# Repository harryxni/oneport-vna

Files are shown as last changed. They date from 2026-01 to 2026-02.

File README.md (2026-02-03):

# **One Port VNA**

 My attempt at designing a one port VNA and to learn some RF fundamentals and technqiues. The goal here is to build a simple working S11 (reflection) VNA with minimal RF complexity.

## Architecture

The design will be based around the ADL 5960, a VNA frontend that should simplify many design considerations by black-boxing a few components of typical VNAs. Besides the ADL 5960, we will require an ADC stage, digital processing, and an RF source and a clock source.

Let's set some target design specs:

* Frequency: 10 MHz - O(1) GHz

* TBD

## Repo Structure

- kicad/ Schematic and PCB design files

- docs/ Notes on design and theory, block diagrams, data sheets and user guides

- firmware/ ADC, FPGA code etc.

- simulations/ SPICE, RF simulations

- fabrication/ Fabrication outputs by kicad

- scripts/ Data processing and plotting

## Results

Results will be posted here as I progress. 

#### Step 1: Simulating Idealized Components

GOAL: Develop a system-level simulation using idealized components to return $\Gamma$ and $S_{11}$. It will consist of a voltage source (V_1), a source impedance ($R_{\text{src}}$) and a DUT ($R_{\text{load}}$).

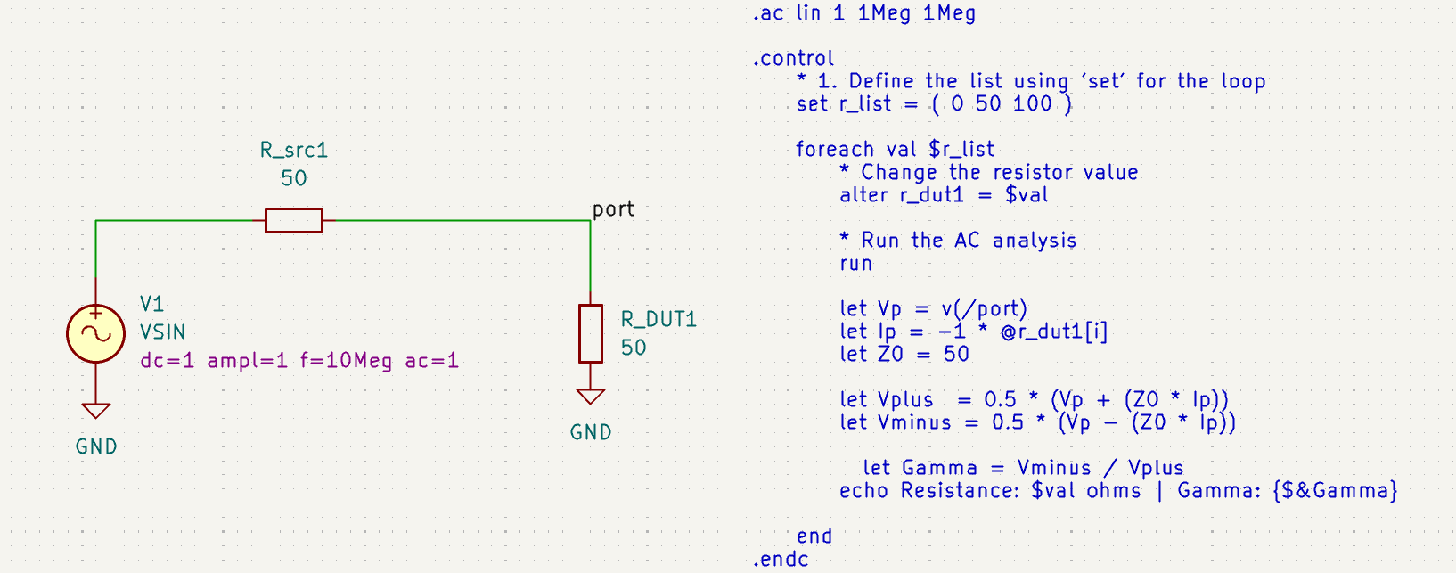
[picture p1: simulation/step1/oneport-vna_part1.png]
 

The schematic and ngspice directive is shown above. 

A few notes on this...KiCAD has some quirks when running spice simulations (coming from xschem). Specifically, running plotting commands within .control does not work since KiCAD uses its own plotting software. This creates an issue since defining vectors and variables within the KiCAD simulator and plotter is very clunky. Here, I remedy this by running a single point in the .ac analysis and just printing $\Gamma$, since I don't expect any change at different frequencies. In the future, I'll have to use wrdata to export data and use python to plot. Also, .step does not work in KiCAD, so I had to use a foreach loop which edits the resistance of R_DUT, rather than setting a param and stepping through.

Results are below with some of the spice output cleaned up. They are as expected...

```
Resistance: 0 ohms | Gamma: -1
Resistance: 50 ohms | Gamma: 0
Resistance: 100 ohms | Gamma: 0.333333
```

#### Step 2: A more realistic simulation

GOAL: Introduce realistic imperfection into the model, such as parasitics and source matching errors and using a realistic coupler (ie a Return loss bridge) to model effects of error in measurement. 

##### 2a: VNA with Parasitics

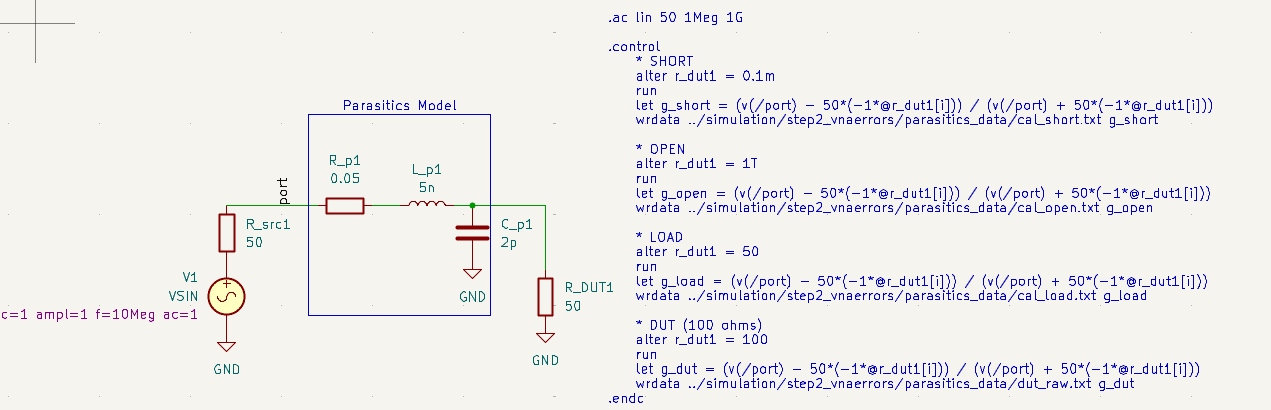
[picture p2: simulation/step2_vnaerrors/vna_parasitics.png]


In this model, we've simply introduced a set of parasitics: a series resistor and inductor and a shunt capacitor, with some arbitrary values. We run the simulation in 4 different scenarios: Open, Short, Load match (OSL) and a DUT ($R_{load}=100$  $\Omega$). The OSL measurement provides a calibration for the errors which are introduced via the parasitics. These are then calculated and used to correct for the DUT measurement.

The exact calculations and data processing are done in [this notebook](simulation/step2_vnaerrors/). The results of the OSL measurements are shown here:

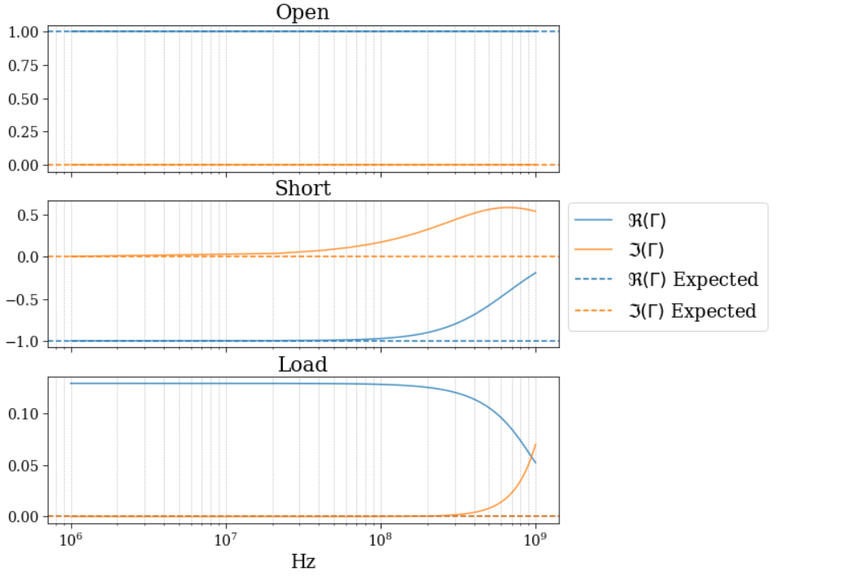
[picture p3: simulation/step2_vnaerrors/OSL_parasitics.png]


Using these measurements in comparison to the expected values, we calculate out the error terms ($E_{dl}$, $E_{sf}$ and $E_{rf}$) and use them for the correct $\Gamma_{DUT}$ measurement:

$\Gamma= \frac{\Gamma_m -E_{dl}}{E_{rf} + E_{sf}(\Gamma_m - E_{dl})}$

The effects of this correction are shown below and compared to the expected value. 

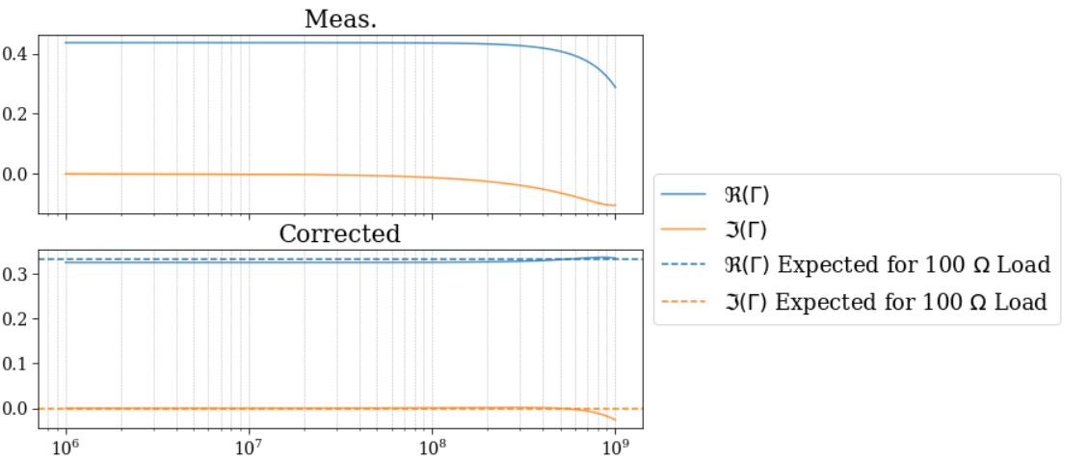
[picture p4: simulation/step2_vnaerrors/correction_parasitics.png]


##### 2b: VNA with Directional Coupling

Here, we will simulate the directional coupling found in the ALD5960 by implementing a bridge. I believe it is simplest to just use a wheatstone bridge in this case, since the ALD5960 does a lot of the handling of the RLB measurements. 

I've addded some parasitics in the system as well. 

Below shows the simulated ciruit:

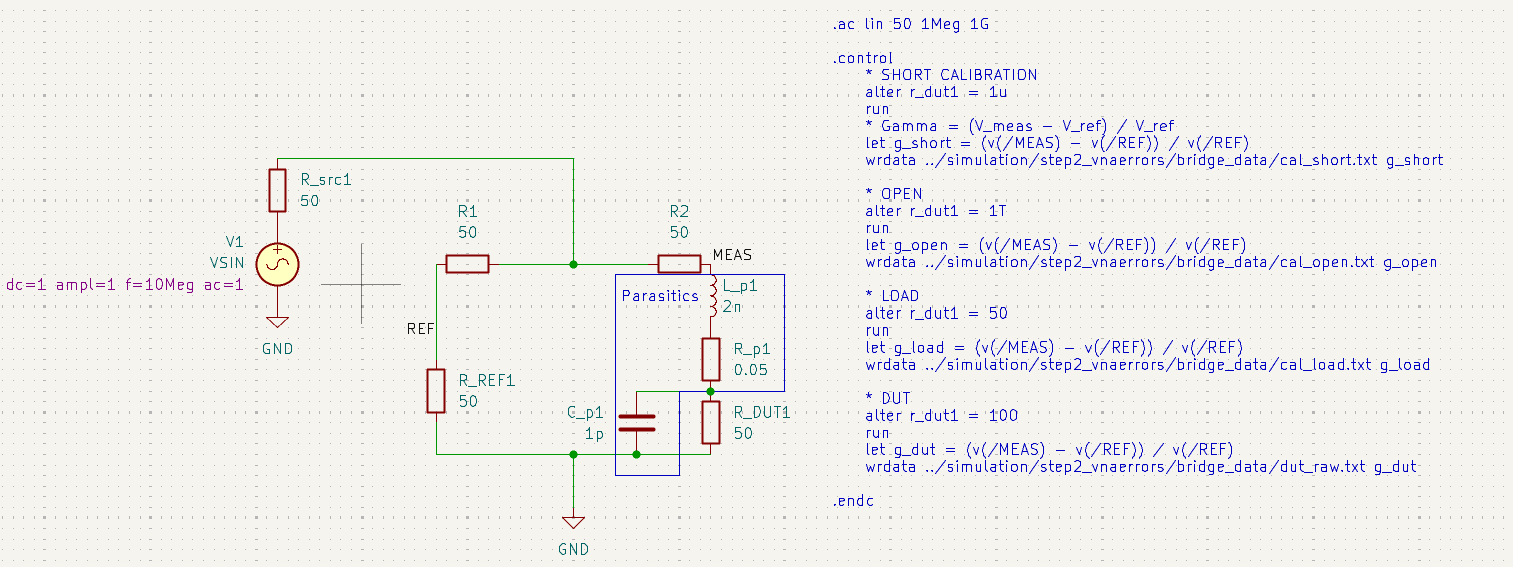
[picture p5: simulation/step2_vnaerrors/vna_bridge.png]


The results of the OSL calibration and the corrected DUT are below:

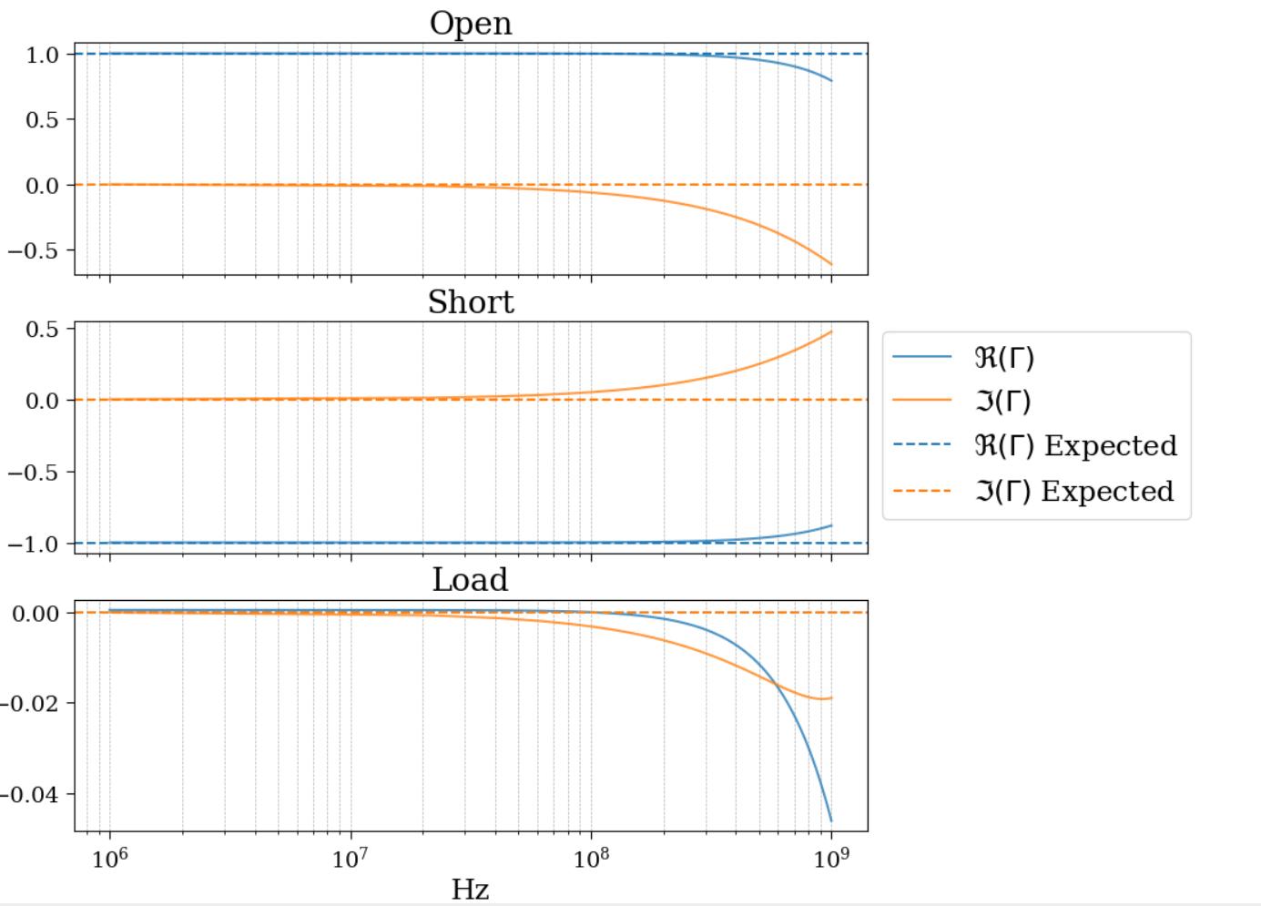
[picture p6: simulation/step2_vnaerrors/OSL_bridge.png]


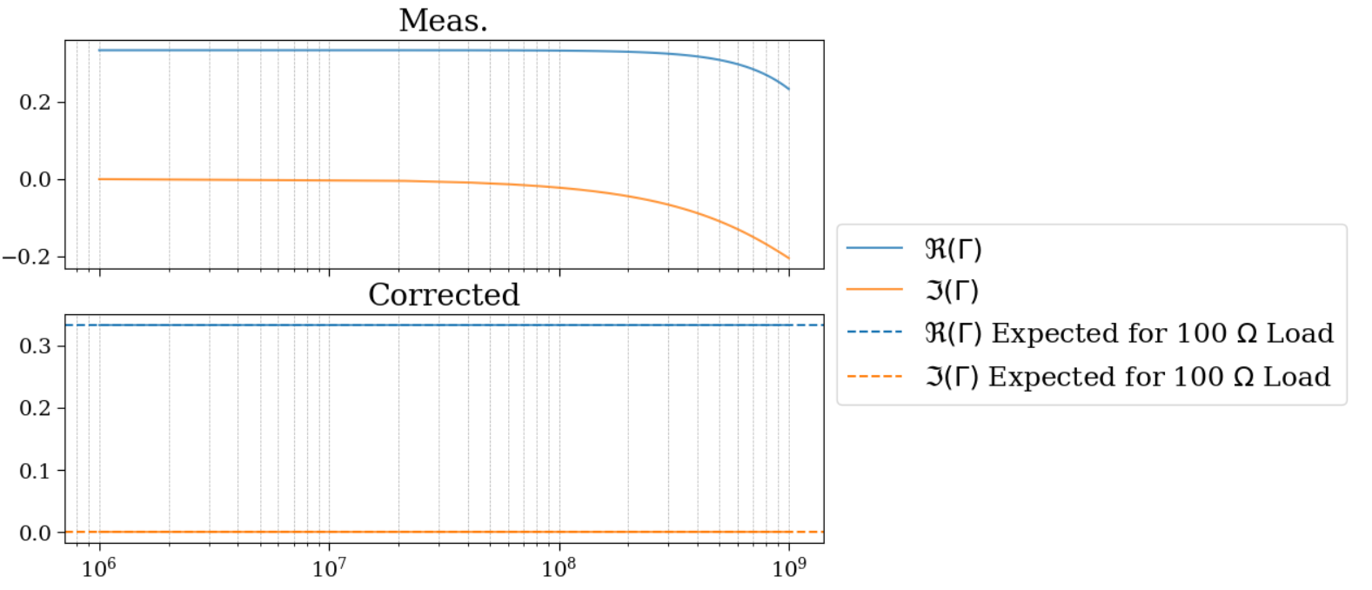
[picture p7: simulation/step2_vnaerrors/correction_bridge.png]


These results show that we can take the VNA model, "break" it with non-ideal but realistic parts and then use a calibration + correction to fix it. 

##### 2c: Introducing a transmission line

In the previous step, the DUT and the REF measurements were taken at the same place.  

#### Step 3: Schematic Integration

GOAL: Integrate the ADL5960, ADC, RF source and clocking (could possibly be off-board), and supporting circuitry into a complete schematic.

Details are in this [README](kicad/README.md). 

The board schematic can be divided into a few sections:

##### Power Management

Let's work around the the Analog Devices recommended voltage regulator: [the LT3041.](https://www.analog.com/en/products/lt3041.html) The required supply voltage is 5 V for the ADL5960 measurement, and 3.3V for the SPI. The regulator provides 1 A of current, which should be more than enough. 

First Draft Completed, see [kicad/README.md](kicad/README.md)

##### RF Source

We'll add an on-board RF source to achieve high O(1) GHz frequencies, but in the case that it breaks/doesn't work. we will add a jumper to an SMA connector to allow for off-board frequencies via an external AFG.

It seems the [ADF4351](https://www.analog.com/en/products/adf4351.html) is a decent choice, with a range from 35 MHz to 4.4 GHz. If we want a higher range, we can move up to the [4371](https://www.analog.com/en/products/adf4371.html).  It will require a 3.3 V supply. We can AC couple the output to the measurement core. 

We will require an external reference clock. We can pick a Temperature Compensated Crystal Oscillator. 

##### Filter Bank

We need a very clean RF stimulus, but typical digital RF sources do not provide sine waves but square waves, which are full of harmonics. We can filter these frequencies out using low pass filters, but since a VNA operates over a large frequency range, a bank of filters is required.

Let's say we start with a LO (local oscillator) frequency for mixing of 2 MHz.

##### Measurement Core

As mentioned, we will use the ADL5960. 

We'll provide an external SMA connection for DUT.

##### I/Q Signal Path

The Intermediate Frequency (IF) output of the ADL5960 is differential and will be connected to low pass filters.    

##### Digital Control

This might be easiest to do off board, either via a microcontroller or FPGA. We'll need to provide an 8 pin header: VCC, GND, MOSI, MISO, SCK, CS_LO, CS_VNA. 

#### Step 4: Layout

GOAL: Route and place the PCB. 
[...]

#### Step 5: Firmware

GOAL: Implement ADC capture, vector extraction and calibration routines. Generate results.

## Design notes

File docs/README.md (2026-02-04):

# **VNA Math**

The VNA calculates the ratio of the reflected wave to the incident wave

### **Step 1: Voltage to Complex Vector**

For both the **Reference** ($V\_{ref}$) and **Reflected** ($V\_{rl}$) channels, we calculate:

$V = I + jQ$

In the ALD5960, this is done using an I/Q measurement via an Intermediate Frequency (IF). The input is:

$V(t) = A\cos{(2\pi f_rt+\phi)}$

and is mixed with a separate frequency $f_{lo}$ to form:

$I = V(t) \times cos(2\pi f_{lo}t)$

$Q=V(t) \times \sin(2\pi f_{lo}t)$

Using some trig identities gets us:

$I=A/2\cos(2\pi f_{IF}t+\phi)$

$Q = A/2 \sin(2\pi f_{IF} + \phi)$

where $f_{IF} = f_r -f_{LO}$, known as the intermediate frequency. The

### **Step 2: Raw Reflection Coefficient**

The raw measurement ($\Gamma_{raw}$) is the complex division of these two vectors:

$\Gamma_{raw} = \frac{V_{rl}}{V_{ref}}$  

## Step 3: **The 3-Term Error Model (Calibration)**

We use **OSL (Open, Short, Load)** calibration to correct for the following three systematic errors:

1. **Directivity ($E_D$):** Leakage inside the coupler where the forward signal "bleeds" into the reflection port.  
2. **Source Match ($E_S$):** Reflections from the VNA's own port bouncing back toward the DUT.  
3. **Reflection Tracking ($E_{RT}$):** The frequency response (gain/loss/tilt) of the cables and internal traces.

### **Calibration Formula**

After measuring OSL standards, the true reflection coefficient ($\Gamma_{actual}$) is recovered from the raw measurement using:

$\Gamma_{actual} = \frac{\Gamma_{raw} - E_D}{E_{RT} + E_S(\Gamma_{raw} - E_D)}$ 

## **Derived Measurements**

Once $\Gamma_{actual}$ is calculated, we can derive standard RF metrics:

* **Return Loss (dB):** $-20 \log\_{10}(|\Gamma|)$  
* **VSWR:** $\frac{1 + |\Gamma|}{1 - |\Gamma|}$  
* **Impedance ($Z$):** $50 \cdot \frac{1 + \Gamma}{1 - \Gamma} \rightarrow (R + jX)$

# **Filter Bank, IF selection**

## Stimulus and Harmonic Content

We can generally assume an RF source wave that's roughly square, which is primarily constructed of odd-order harmonics:

$x(t) \propto \sin(\omega t) + \frac{1}{3} \sin(3\omega t) + \frac{1}{5}\sin(5 \omega t) + \dots$ 

To create an ideal sine wave source, we can use a low-pass filter to filter out these harmonics. However, because a VNA operates over a wide range of frequencies, we must select different filters to operate over different bands within the full frequency range, known as the **Source Filter Bank**.

## Frequency Planning

An additional part of the filter selection criteria is consideration of the Local Oscillator (LO) frequency and the Intermediate Frequency (IF), related by:

$f_{IF} = |f_{RF} - f_{LO\_eff}|$

Generally, we pick $f_{IF}$ to be constant (e.g., $100\text{ kHz}$ or $1\text{ MHz}$) and have $f_{LO}$ track the stimulus $f_{RF}$. We typically use **High-Side Injection** ($f_{LO} > f_{RF}$) to ensure the phase polarity remains consistent throughout the sweep.

## Harmonic Mixing and Aliasing

The issue with square-ish waves is **Harmonic Mixing**. Even if the fundamental produces the desired $f_{IF}$, the harmonics in the stimulus and LO interact:

$f_{IF\_harmonic} = |m \cdot f_{RF} - n \cdot f_{LO\_eff}|$

For example, the 3rd harmonics produce a "ghost" signal at $f_{IF}^3 = |3 f_{RF} - 3f_{LO}|$, which is exactly $3 \times f_{IF}$. While the LPF on the IF output can easily remove this $3\text{ MHz}$ signal, the real danger is **Aliasing**.

In real hardware, duty cycle imperfections (signals not being exactly 50/50) create even-order harmonics ($2f, 4f$). If these are present in the LO, a harmonic like $2f_{LO}$ can mix with a stimulus harmonic like $2f_{RF}$ or $3f_{RF}$ to create products that land exactly near$f_{IF}$.

One method used to combat this duty cycle asymmetry is using the LO divider, which is offered on the ALD5960. I'm not entirely clear on why this is, but diving the LO input suppresses the even harmonics. 

### Example:

Let's work through a VNA system to illustrate this. We want a VNA that operates from 100 MHz to 10 GHz for example. We select an IF of $f_{IF}= 1 $ MHz arbitrarily but can be easily digitized by ADCs and processed by an FPGA. 

Let's take a look at the low end 100 MHz measurement point. We will need to set a target $f_{LO}=101$ MHz. We can achieve this easily using the internal frequency divider of $N=4$, which means our $f_{LO}^{\text{Injected}} = 404$ MHz.

 We can also filter out the stimulus frequency harmonics. Our primary concern is the 3rd harmonic of 300 MHz, which we can cut off with a LPF. 

The choice of LPF cutoff frequency $f_c$ is dependent on the order of filter (which defines the degree of attenuation at a given frequency) and this decision then directly decides the band range $f_{max}$, where the band goes from $100 \text{ MHz}-f_{max}$.

The Gain of a filter:

$G = \frac{1}{1+(f/f_c)^{2n}}$

where $n$ is the order of the filter. Say we choose a 5th order LPF and we target an   ~ ~-20db (1% power) reduction at the harmonic, then a possible cutoff frequency $f_c= 200$ MHz. That means $f_c\approx (3/1.5) f_{RF}=2f_{RF}$. 

Then we choose a max stimulus frequency. We should target an $f_{max}$ that retains ~90%/-0.5 dB of the original signal. This means a $f_{max}\approx 0.8 f_c$. 

The full filter bank is then:

| Band | RF Source Range | LO Divider | Injected $f_{LO}$ | Source LPF cutoff |
| ---- | --- | --- | --- | --- |
| 1 | 100 - 160 MHz | 4 | 404 - 644 MHz | 200 MHz |
| 2 | 160  - 250 MHz  | 4 | < 1GHz | 320 MHz |
| 3 | 250 - 400 MHz | 4 | < 2 GHz | 510 MHz |
| 4 | 400 - 650 MHz | 2 | < 2 GHz | 815 MHz |
| 5 | 650 - 1000 MHz  | 2 | <2 GHz | 1.3 GHz |
| 6 | 1 - 1.6 GHz | 2 | $f_{RF}$ | 2 GHz |
| 7 | 1.6  - 2.5 GHz  | 1 | $f_{RF}$ | 3.2 GHz |
| 8 | 2.5 - 4 GHz | 1 | $f_{RF}$ | 5.1 GHz |
| 9 | 4 - 6.5 GHz | 1 | $f_{RF}$ | 8.15 GHz |
| 10 | 6.5 - 10 GHz | 1 | $f_{RF}$ | 10.3 GHz |

Okay, so these 10 bands are a bit crazy... And I don't believe its easily achievable in engineering. That is, there will be tradeoffs and we can use things like higher-order filters, lightening some of the "rules" I set and also relying on post-processing of the IF signal to alleviate some of these bands. 

Ideas:

* At lower frequncies ( higher LO divider numbers), we can count on having 0 even harmonics, which can allow us to increase the low frequency band sizes by a lot.

* 7th order filters over some of the ranges, particularly the low or mid bands where we can greatly increase the band size. 

* 

After some product browsing, a reasonable target is probably a filter bank of 6 for an SP6T. This can be done.

I've browsed the MiniCircuits LPF catalog, so let's build out a 6 filter bank. 

Attempt 2: 

| Band | RF Source Range | LO Divider | Filter | F3 |
| ---- | --- | --- | --- | --- |
| 1 | 100 - 225 MHz | 4 | LFCN-225+  | 460 MHz  |
| 2 | 225-  450 MHz | 4 | LFCN-490+  | 800 MHz  |
| 3 | 450 - 1200 MHz  | 2 | LFCN-1200+ | 1.85 GHz |
| 4 | 1.2 - 3 GHz | 1 | LFCN-3000+ | 4.5 GHz  |
| 5 | 3 - 6 GHz | 1 | LFCN-6000+ | 8.5 GHz  |
| 6 | 6 - 10 GHz | 1 | LFCW-103+  | 13+ GHz  |

where F3 is the (-20 db) attenuation point of the filter, and the number in the Filter name refers to the (-1 db) point. 

Another thing I'm realizing we can take advantage of here is the overlap between bands. For example, at 225 MHz, the primary harmonic is at 675, which is well blocked in band 1. However, in band 2, this 675 MHz frequency is not well attenuated. Perhaps, we can increase some amount of overlap in between bands to improve measurements. 

Again, we are trying to take advantage of the fact that with a higher LO division, we get more perfect square waves to mix with, thus removing any of the even harmonics. 

Let's build out a python simulation in a notebook to visualize and see the effects of these filters and also understand the results of the final filtering and I/Q sampling.

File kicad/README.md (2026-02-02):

# Schematic Work

This README will be used to keep my notes and details as I work up the schematic in sections.

### Power

First Draft:

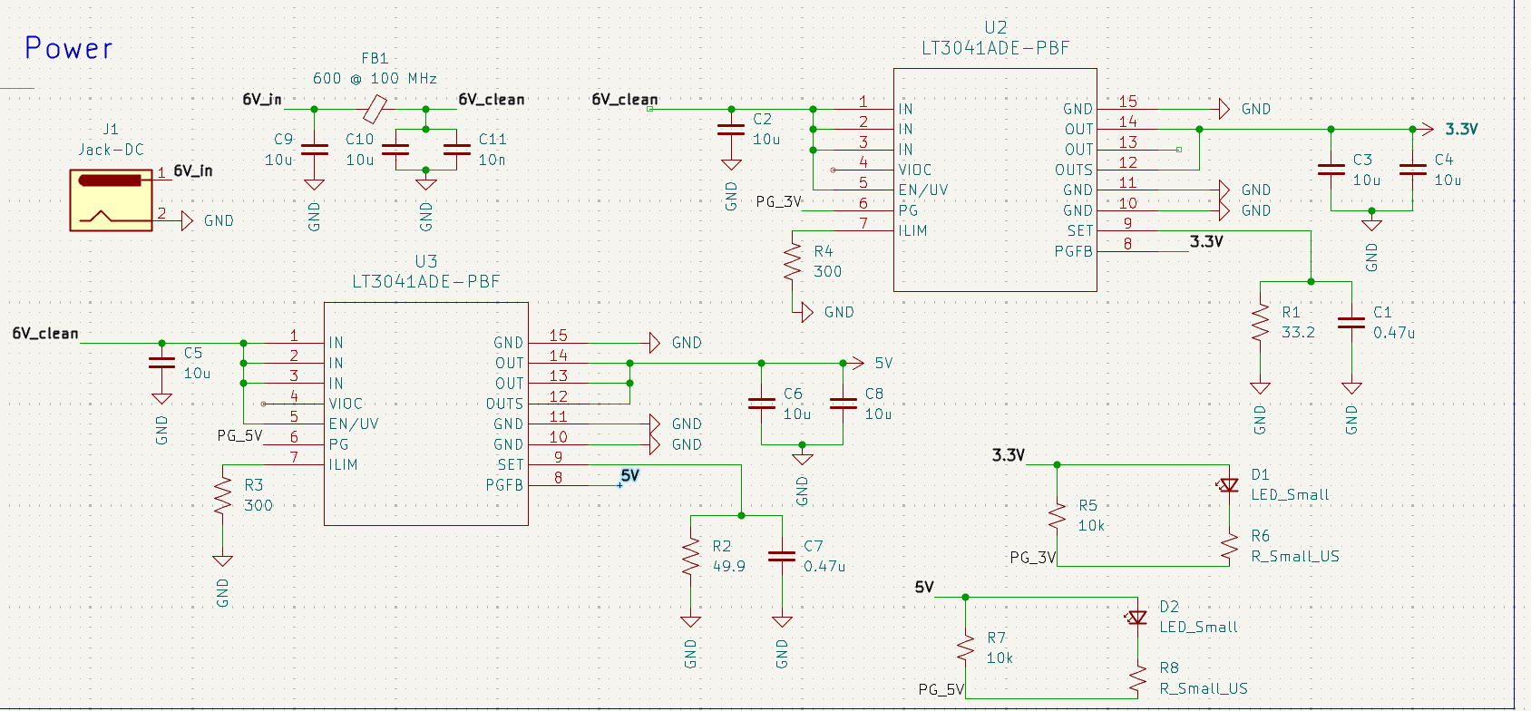
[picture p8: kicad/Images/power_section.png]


Designed around two LT3041 regulators to provide 5 V and 3.3 V levels. 

We will provide a 6 V input from a benchtop supply, connected to the board via DC barrel jack. 

A Pi-filter network consisting of a ferrite bead and capacitors filters out any high frequency noise. 

The output voltages of the LT3041 are set by a resistor to GND on the SET pin:

$R_{set}= V_{out}/100~\mu A$

and the output current limit is set by a resistor on the ILIM pin:

$R_{iout} = \frac{150~\text{mA} \times \text{k}\Omega}{I_{lim}}$

The caps are the input and output of the regulator are used for more noise filtering, and their placement in the layout will be important.

In addition, I've placed an LED indicator at the output of the regulator, using the PG and PGFB pins. I'm not entirely sure I've used the PGFB pins correctly honestly, since there aren't any good examples on the datasheet. And, I haven't decided the exact LEDs to use yet either, but I've gotten a start here. Perhaps, I can just use the voltage rails directly anyway, instead of PG.

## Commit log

2026-01-28 reorganized, VNA math notes
    [oneport-vna.kicad_pcb, oneport-vna.kicad_sch]
2026-01-29 completed phase 1: idealized simulation using spice devices
    [step1_idealized_vna.kicad_sch]
2026-01-30 parasitics simulation
    [step2a_vna_errors_parasitics.kicad_sch]
2026-01-30 added ADL5960 files
    [oneport-vna.kicad_pcb, oneport-vna.kicad_sch]
2026-01-31 step 2b: simulated vna with a bridge
    [step2b_vna_RLB.kicad_sch]
2026-02-02 first draft of power management section + notes
    [oneport-vna.kicad_sch]
2026-02-03 added some notes in docs about filter bank, LO calculations, should be useful
2026-02-04 started simulated filter bank, functions should be working but getting weird results
2026-02-05 Wave gen, mixing, filtering and I/Q meas simulation working, can be used for filter bank selection
